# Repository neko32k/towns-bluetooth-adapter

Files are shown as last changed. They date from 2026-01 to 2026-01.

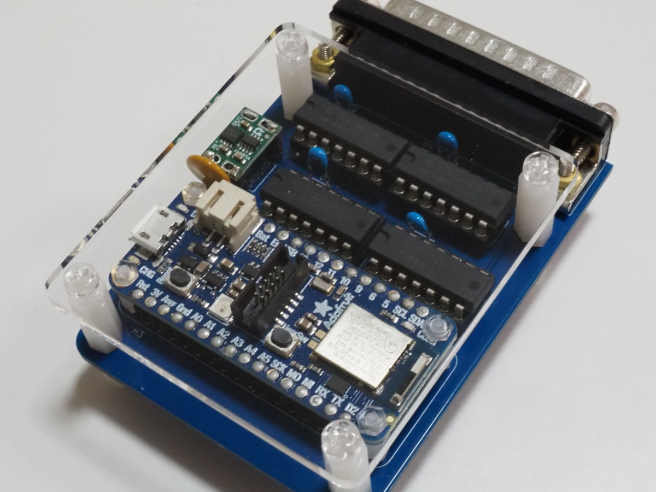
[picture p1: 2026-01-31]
assets/towns-bluetooth-adapter.jpg

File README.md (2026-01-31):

# FM TOWNS Bluetooth Adapter (towns-bluetooth-adapter)

This repository contains firmware, circuit diagrams, and documentation for a Bluetooth input adapter for FM TOWNS, using Adafruit Feather nRF52840. The goal is to enable modern Bluetooth keyboards, mice, and controllers to behave as HID devices for FM TOWNS systems.

このリポジトリは、Adafruit Feather nRF52840 を使用して FM TOWNS に Bluetooth 入力を追加するためのファームウェア、回路図、手順書をまとめたものです。Bluetooth キーボード／マウス／コントローラを FM TOWNS 側で HID として使えるようにすることを目標とします。

Disclaimer / 免責事項
- This project is an independent hobby project and is NOT affiliated with or endorsed by the FM TOWNS trademark owner or any commercial entity.
- 本プロジェクトは個人の趣味プロジェクトです。FM TOWNS の商標所有者や企業とは関係ありません。回路や接続による機器の故障や損害について作者は責任を負いません。実施は自己責任でお願いします。

Repository contents / 目次
- /arduino — Arduino スケッチ
- /kicad — KiCad プロジェクト（回路図・PCB）  
- /assets — 写真・動画・GIF  
- LICENSE — ライセンス（MIT）  

Requirements / 前提
- Adafruit Feather nRF52840 Express (or compatible)  
- FM TOWNS with accessible 5V power pin  
- Bluetooth input devices for testing

Companion blog / ブログ
- Project blog and notes: https://www.nk3-dev.net/  

Dependencies / 依存関係
This repository vendors `CircularQueue` (renamed to `CircularQueue.h`) from Francis‑Magallanes/CircularQueue.  
License: MIT — included in `licenses/CircularQueue_LICENSE.txt`.

本プロジェクトは `CircularQueue`（`CircularQueue.h` として同梱）を使用しています。上流は MIT ライセンスです（`licenses/CircularQueue_LICENSE.txt` を参照）。  
Included vendored file path: `arduino/bt_device/CircularQueue.h`

Affiliate disclosure / アフィリエイト表記
- Some links in this repository or the companion blog may be affiliate links (Amazon.co.jp Associate). 
- 本リポジトリおよび関連ブログには Amazon.co.jp 等のアフィリエイトリンクが含まれる場合があります。

License / ライセンス
This project is licensed under the MIT License — see the LICENSE file for details.  
本プロジェクトは MIT ライセンスで配布します。詳細は LICENSE を参照してください。

Author / 作者
- GitHub: neko32k  
- Year / 年: 2026

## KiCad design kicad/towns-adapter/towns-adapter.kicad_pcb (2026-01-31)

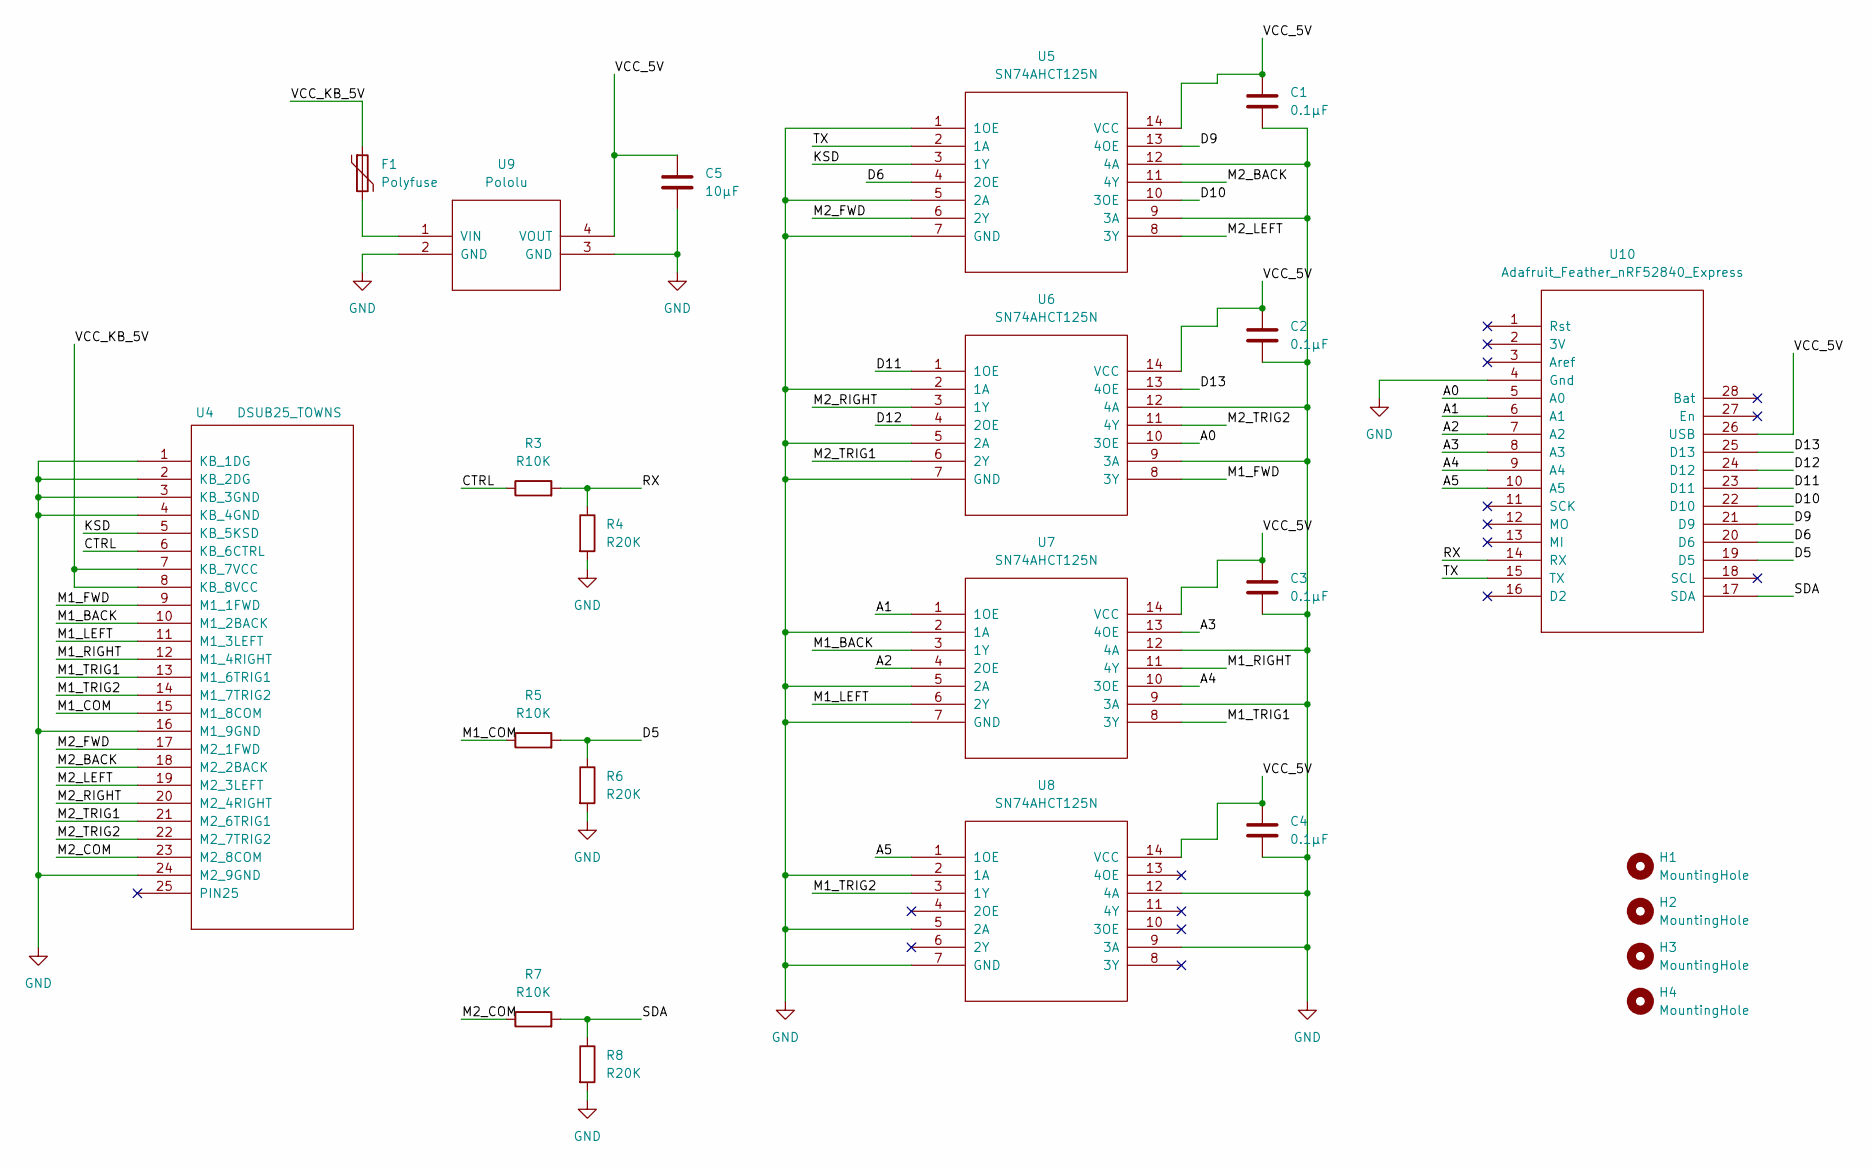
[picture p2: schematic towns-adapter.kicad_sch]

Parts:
C1, C2, C3, C4: 0.1μF; R_Axial_DIN0204_L3.6mm_D1.6mm_P5.08mm_Horizontal
C5: 10µF; CIP_CAPACITOR_C_1206_3216Metric_Pad1.33x1.80mm_HandSolder
F1: Polyfuse; R_Axial_DIN0204_L3.6mm_D1.6mm_P5.08mm_Horizontal
H1, H2, H3, H4: MountingHole; MountingHole_3.2mm_M3
R3, R5, R7: R10K; R_Axial_DIN0204_L3.6mm_D1.6mm_P7.62mm_Horizontal
R4, R6, R8: R20K; R_Axial_DIN0204_L3.6mm_D1.6mm_P7.62mm_Horizontal
U4: DSUB25_TOWNS; MODULE
U5, U6, U7, U8: SN74AHCT125N; MODULE
U9: Pololu; MODULE
U10: Adafruit_Feather_nRF52840_Express; MODULE

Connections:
/A0: U6.10 (3OE), U10.5 (A0)
/A1: U7.1 (1OE), U10.6 (A1)
/A2: U7.4 (2OE), U10.7 (A2)
/A3: U7.13 (4OE), U10.8 (A3)
/A4: U7.10 (3OE), U10.9 (A4)
/A5: U8.1 (1OE), U10.10 (A5)
/CTRL: R3.1, U4.6 (KB_6CTRL)
/D5: R5.2, R6.1, U10.19 (D5)
/D6: U5.4 (2OE), U10.20 (D6)
/D9: U5.13 (4OE), U10.21 (D9)
/D10: U5.10 (3OE), U10.22 (D10)
/D11: U6.1 (1OE), U10.23 (D11)
/D12: U6.4 (2OE), U10.24 (D12)
/D13: U6.13 (4OE), U10.25 (D13)
/KSD: U4.5 (KB_5KSD), U5.3 (1Y)
/M1_BACK: U4.10 (M1_2BACK), U7.3 (1Y)
/M1_COM: R5.1, U4.15 (M1_8COM)
/M1_FWD: U4.9 (M1_1FWD), U6.8 (3Y)
/M1_LEFT: U4.11 (M1_3LEFT), U7.6 (2Y)
/M1_RIGHT: U4.12 (M1_4RIGHT), U7.11 (4Y)
/M1_TRIG1: U4.13 (M1_6TRIG1), U7.8 (3Y)
/M1_TRIG2: U4.14 (M1_7TRIG2), U8.3 (1Y)
/M2_BACK: U4.18 (M2_2BACK), U5.11 (4Y)
/M2_COM: R7.1, U4.23 (M2_8COM)
/M2_FWD: U4.17 (M2_1FWD), U5.6 (2Y)
/M2_LEFT: U4.19 (M2_3LEFT), U5.8 (3Y)
/M2_RIGHT: U4.20 (M2_4RIGHT), U6.3 (1Y)
/M2_TRIG1: U4.21 (M2_6TRIG1), U6.6 (2Y)
/M2_TRIG2: U4.22 (M2_7TRIG2), U6.11 (4Y)
/RX: R3.2, R4.1, U10.14 (RX)
/SDA: R7.2, R8.1, U10.17 (SDA)
/TX: U5.2 (1A), U10.15 (TX)
/VCC_5V: C1.1, C2.1, C3.1, C4.1, C5.1, U5.14 (VCC), U6.14 (VCC), U7.14 (VCC), U8.14 (VCC), U9.4 (VOUT), U10.26 (USB)
/VCC_KB_5V: F1.1, U4.7 (KB_7VCC), U4.8 (KB_8VCC)
GND: C1.2, C2.2, C3.2, C4.2, C5.2, R4.2, R6.2, R8.2, U4.1 (KB_1DG), U4.2 (KB_2DG), U4.3 (KB_3GND), U4.4 (KB_4GND), U4.16 (M1_9GND), U4.24 (M2_9GND), U5.1 (1OE), U5.5 (2A), U5.7 (GND), U5.9 (3A), U5.12 (4A), U6.2 (1A), U6.5 (2A), U6.7 (GND), U6.9 (3A), U6.12 (4A), U7.2 (1A), U7.5 (2A), U7.7 (GND), U7.9 (3A), U7.12 (4A), U8.2 (1A), U8.5 (2A), U8.7 (GND), U8.9 (3A), U8.12 (4A), U9.2 (GND), U9.3 (GND), U10.4 (Gnd)
unnamed: F1.2, U9.1 (VIN)

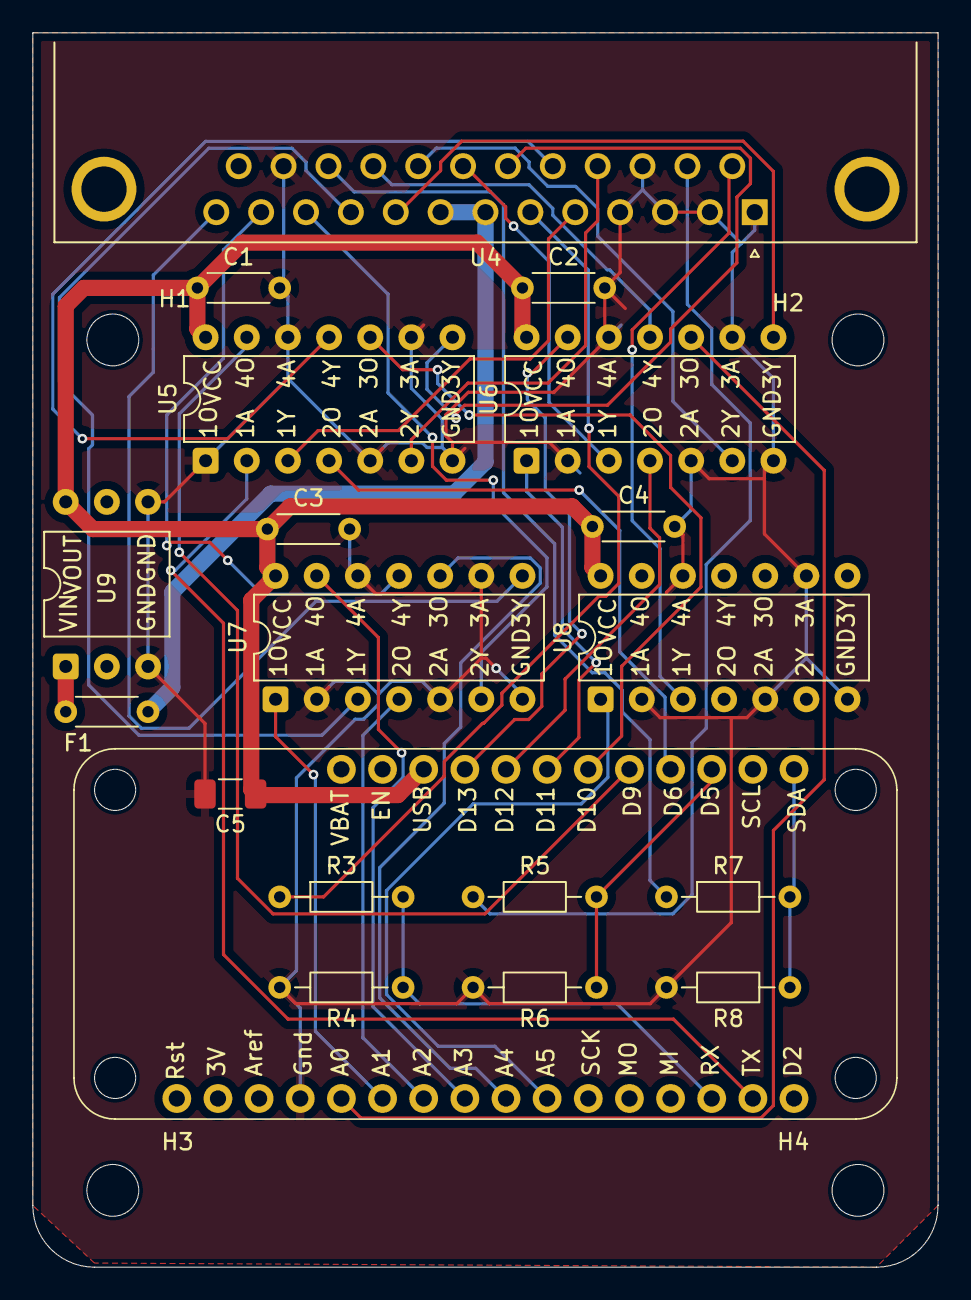
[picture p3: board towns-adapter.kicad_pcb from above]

Board: 2 copper layers, 55.9 x 76.2 mm, 23 parts (0 on the bottom side), 36 nets.

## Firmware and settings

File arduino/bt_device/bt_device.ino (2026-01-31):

#include <bluefruit.h>
#include <Wire.h>
#include "BLEClientHidAdafruitEx.h"
#include "CircularQueue.h"

// --- 設定 ---
#define MAX_CONNECTION    4
#define ENABLE_DEBUG_LOG  0
#define MOUSE_SCALE_NUM   2
#define MOUSE_SCALE_DENOM 3
#define ANALOG_THRESHOLD  10000
#define TURBO_INTERVAL_MS 31      // 連射間隔(ms). 31ms*2=62ms周期 -> 約16連射/秒

// キーボード送信設定
#define ENABLE_BATCH_KEY_PROCESS  // 定義するとキューを一括処理、未定義なら1ループ1キー
#define TOWNS_KEY_DELAY_MS 2      // プレフィックスとコードの間の遅延(ms)

// アクティブポート検出
volatile unsigned long last_strobe_detect_ms[2] = {0, 0};
volatile int active_mouse_port = -1; // -1:なし, 0:ポート0, 1:ポート1

#if ENABLE_DEBUG_LOG
  #define DBG_Printf(...)    Serial.printf(__VA_ARGS__)
  #define DBG_Print(...)     Serial.print(__VA_ARGS__)
  #define DBG_Println(...)   Serial.println(__VA_ARGS__)
#else
  #define DBG_Printf(...)
  #define DBG_Print(...)
  #define DBG_Println(...)
#endif

// --- ピン定義 (マウス / ジョイパッド) ---
// ポート0 ストロボ: SDA (22番ピン)
// ポート1 ストロボ: D5  (5番ピン)
const int PIN_STROBE_P0 = 22;
const int PIN_STROBE_P1 = 5;

// 出力ピン (0-5: ポート0, 6-11: ポート1)
// マッピング: 0=上/D0, 1=下/D1, 2=左/D2, 3=右/D3, 4=Trig1/A, 5=Trig2/B
// 物理ピン:
// P0: 6, 9, 10, 11, 12, 13
// P1: A0, A1, A2, A3, A4, A5
const uint8_t OUT_PINS[] = {
  6,  9, 10, 11, 12, 13,  // ポート 0
  A0, A1, A2, A3, A4, A5  // ポート 1
};

// --- マウスの状態 ---
volatile int16_t mouse_accum_x[2] = {0, 0}; 
volatile int16_t mouse_accum_y[2] = {0, 0};
volatile int16_t latch_x[2] = {0, 0};
volatile int16_t latch_y[2] = {0, 0};
volatile uint8_t mouse_btns[2] = {0, 0};
volatile uint8_t strobe_seq[2] = {0, 0};
volatile unsigned long last_strobe_us[2] = {0, 0};
unsigned long last_strobe_ms_check[2] = {0, 0};
bool has_mouse[2] = {false, false};

// --- キーボードの状態 ---
const uint8_t FMR_PREFIX_MAKE  = 0xA0; // 0x80 | 0x20(JIS)
const uint8_t FMR_PREFIX_BREAK = 0xB0; // 0x90 | 0x20(JIS)
#define FMR_KEY_TABLE_SIZE       256
const unsigned long SERIAL_BAUD = 9600;

struct KeyEvent {
  uint8_t code;
  bool isPress;
};
Queue<KeyEvent, 64> key_queue;

// --- Xboxコントローラー用レポート構造体 ---
typedef struct __attribute__((packed)) {
  int16_t x; int16_t y; int16_t z; int16_t rz;
  uint16_t brake; uint16_t gas;
  uint8_t hat; uint8_t btn1; uint8_t btn2; uint8_t padding;
} xbox_report_t;

typedef struct {
  uint16_t conn_handle;
  BLEClientHidAdafruitEx hid;
  hid_keyboard_report_t last_kbd_report;
  hid_mouse_report_t    last_mse_report;
  xbox_report_t         last_xbox_report;
} prph_info_t;

prph_info_t prphs[MAX_CONNECTION];

// --- FMRキーコード変換テーブル ---
uint8_t usb2fmr[FMR_KEY_TABLE_SIZE]; 

// --- ログバッファ ---
#if ENABLE_DEBUG_LOG
#define LOG_BUF_SIZE 64
typedef struct {
  unsigned long time;
  uint8_t port;
  uint8_t seq;
  int16_t latch;
  uint8_t nibble;
  uint8_t raw_pins; // D0-D3の状態 (ビットマスク)
  uint8_t strobe_level; // ストロボピンの状態
} strobe_log_t;

volatile strobe_log_t strobe_logs[LOG_BUF_SIZE];
volatile uint8_t log_head = 0;
volatile uint8_t log_tail = 0;

void push_strobe_log(uint8_t p, uint8_t s, int16_t l, uint8_t n, uint8_t pins, uint8_t st_lvl) {
  uint8_t next = (log_head + 1) % LOG_BUF_SIZE;
  if (next != log_tail) {
    strobe_logs[log_head].time = millis();
    strobe_logs[log_head].port = p;
    strobe_logs[log_head].seq = s;
    strobe_logs[log_head].latch = l;
    strobe_logs[log_head].nibble = n;
    strobe_logs[log_head].raw_pins = pins;
    strobe_logs[log_head].strobe_level = st_lvl;
    log_head = next;
  }
}
#endif

// --- 前方宣言 ---
void processKeyboardReport(hid_keyboard_report_t* report, hid_keyboard_report_t* last_report);
void processMouseReport(hid_mouse_report_t* report, hid_mouse_report_t* last_report, int port_idx);
void processXboxReport(xbox_report_t* report, xbox_report_t* last_report, int port_idx);
void sendTownsKey(uint8_t code, bool isPress);
void processKeyQueue();
void handleStrobe(int port_idx);
int findConnHandle(uint16_t conn_handle);
void initFMRTable();
void setOut(uint8_t pin_idx_local, bool bit_val, int port_base);

// --- コールバック ---
void kbd_callback_0(hid_keyboard_report_t* report) { processKeyboardReport(report, &prphs[0].last_kbd_report); }
void kbd_callback_1(hid_keyboard_report_t* report) { processKeyboardReport(report, &prphs[1].last_kbd_report); }
void kbd_callback_2(hid_keyboard_report_t* report) { processKeyboardReport(report, &prphs[2].last_kbd_report); }
void kbd_callback_3(hid_keyboard_report_t* report) { processKeyboardReport(report, &prphs[3].last_kbd_report); }

void mse_callback_0(hid_mouse_report_t* report) { processMouseReport(report, &prphs[0].last_mse_report, 0); }
void mse_callback_1(hid_mouse_report_t* report) { processMouseReport(report, &prphs[1].last_mse_report, 1); }
void mse_callback_2(hid_mouse_report_t* report) { processMouseReport(report, &prphs[2].last_mse_report, 0); }
void mse_callback_3(hid_mouse_report_t* report) { processMouseReport(report, &prphs[3].last_mse_report, 1); }

void (*kbd_callbacks[MAX_CONNECTION])(hid_keyboard_report_t*) = { kbd_callback_0, kbd_callback_1, kbd_callback_2, kbd_callback_3 };
void (*mse_callbacks[MAX_CONNECTION])(hid_mouse_report_t*)    = { mse_callback_0, mse_callback_1, mse_callback_2, mse_callback_3 };

// Xbox コールバック
void xbox_input_callback_impl(uint16_t conn_handle, uint8_t* data, uint16_t len) {
  if (len == 16) {
    int id = findConnHandle(conn_handle);
    if (id >= 0) {
      // ゲームパッド 1->ポート0, ゲームパッド 2->ポート1 にマッピング (ロジック: id % 2)
      processXboxReport((xbox_report_t*)data, &prphs[id].last_xbox_report, id % 2);
    }
  }
}
void xbox_callback_0(BLEClientCharacteristic* chr, uint8_t* data, uint16_t len) { xbox_input_callback_impl(prphs[0].conn_handle, data, len); }
void xbox_callback_1(BLEClientCharacteristic* chr, uint8_t* data, uint16_t len) { xbox_input_callback_impl(prphs[1].conn_handle, data, len); }
void xbox_callback_2(BLEClientCharacteristic* chr, uint8_t* data, uint16_t len) { xbox_input_callback_impl(prphs[2].conn_handle, data, len); }
void xbox_callback_3(BLEClientCharacteristic* chr, uint8_t* data, uint16_t len) { xbox_input_callback_impl(prphs[3].conn_handle, data, len); }
void (*xbox_callbacks[MAX_CONNECTION])(BLEClientCharacteristic*, uint8_t*, uint16_t) = { xbox_callback_0, xbox_callback_1, xbox_callback_2, xbox_callback_3 };

// --- ISRラッパー ---
void isr_strobe_p0() { handleStrobe(0); }
void isr_strobe_p1() { handleStrobe(1); }

void setup() {
#if ENABLE_DEBUG_LOG
  Serial.begin(115200);
#endif
  DBG_Println("Towns BT Adapter: Integrated Firmware");

  initFMRTable();

  // GPIO 設定
  for (int i=0; i<12; i++) {
    pinMode(OUT_PINS[i], OUTPUT);
    digitalWrite(OUT_PINS[i], HIGH);
  }
  pinMode(PIN_STROBE_P0, INPUT_PULLUP);
  pinMode(PIN_STROBE_P1, INPUT_PULLUP);
  attachInterrupt(digitalPinToInterrupt(PIN_STROBE_P0), isr_strobe_p0, CHANGE);
  attachInterrupt(digitalPinToInterrupt(PIN_STROBE_P1), isr_strobe_p1, CHANGE);

  // キーボード用UART (nRF52 featherではSerial1が標準)
  Serial1.begin(SERIAL_BAUD, SERIAL_8E1);

  // BLE設定
  Bluefruit.begin(0, MAX_CONNECTION);
  Bluefruit.setName("Towns BT Adapter");
  Bluefruit.setConnLedInterval(250);
  
  for (uint8_t i=0; i<MAX_CONNECTION; i++) {
    prphs[i].conn_handle = BLE_CONN_HANDLE_INVALID;
    prphs[i].hid.begin();
    memset(&prphs[i].last_kbd_report, 0, sizeof(hid_keyboard_report_t));
    memset(&prphs[i].last_mse_report, 0, sizeof(hid_mouse_report_t));
    memset(&prphs[i].last_xbox_report, 0, sizeof(xbox_report_t));
    prphs[i].last_xbox_report.hat = 8; // Hat center (released) initialization
    
    prphs[i].hid.setKeyboardReportCallback(kbd_callbacks[i]);
    prphs[i].hid.setMouseReportCallback(mse_callbacks[i]);
  }

  Bluefruit.Central.setConnectCallback(connect_callback);
  Bluefruit.Central.setDisconnectCallback(disconnect_callback);
  Bluefruit.Security.setSecuredCallback(connection_secured_callback);
  
  Bluefruit.Scanner.setRxCallback(scan_callback);
  Bluefruit.Scanner.restartOnDisconnect(true);
  Bluefruit.Scanner.setInterval(160, 80); 
  Bluefruit.Scanner.filterUuid(BLEUuid(0x1812)); 
  Bluefruit.Scanner.useActiveScan(true);
  Bluefruit.Scanner.start(0); 
}

void loop() {
  unsigned long now = millis();
  
  // キーキューの処理
  processKeyQueue();

  // --- ログ出力 ---
#if ENABLE_DEBUG_LOG
  while (log_head != log_tail) {
      strobe_log_t l;
      l.time     = strobe_logs[log_tail].time;
      l.port     = strobe_logs[log_tail].port;
      l.seq      = strobe_logs[log_tail].seq;
      l.latch    = strobe_logs[log_tail].latch;
      l.nibble   = strobe_logs[log_tail].nibble;
      l.raw_pins = strobe_logs[log_tail].raw_pins;
      l.strobe_level = strobe_logs[log_tail].strobe_level;
      
      log_tail = (log_tail + 1) % LOG_BUF_SIZE;
      
      DBG_Printf("[Port%d P:%d] Strobe:%d Latch:%d Nib:%X PinOut:%02X\n", 
                 l.port, l.seq, l.strobe_level, l.latch, l.nibble, l.raw_pins);
  }
#if ENABLE_DEBUG_LOG
  static unsigned long last_alive = 0;
  if (now - last_alive > 5000) {
     DBG_Println("[Sys] Status Report:");
     for(int p=0; p<2; p++) {
        unsigned long idle = now - last_strobe_ms_check[p];
        DBG_Printf("  Port%d: MouseMode=%d, StrobeIdle=%lums, GpdActive=%d\n", 
                   p, has_mouse[p], idle, (idle >= 200 && !has_mouse[p]));
     }
     last_alive = now;
  }
#endif
#endif

  // ゲームパッド出力の更新 (マウスモードでない場合)
  for(int p=0; p<2; p++) {
    // マウスモードが有効な場合でも、このポートが「アクティブなマウスポート」として確定していない場合は
    // ゲームパッドとして振る舞うことを許可する（これが「そうで無い方はゲームパッドにする」の実装）。
    // active_mouse_port は handleStrobe() で TOWNSからのストロボ信号を受けたときに更新される。
    if (has_mouse[p] && active_mouse_port == p) {
       continue;
    }

    // 最近ストロボがあった場合（レガシーチェック）、スキップ
    // FM-TOWNS本体が常にストロボ信号(ポート7)をポーリングしている可能性がある。
    // その場合、ここでブロックするとゲームパッド信号が出力されないため、コメントアウトする。
    // (マウスモードの排他制御は has_mouse[p] で十分に行われている)
    // if (now - last_strobe_ms_check[p] < 200) {
    //    continue; 
    // }
    
    // このポートのアクティブなゲームパッドを探す
    xbox_report_t* xb = NULL;
    
    // 【修正】1台のコントローラー(ID=0)だけでポート0/1の両方を操作可能にする(接続ミスやポート入替対策)
    // ID=0がつながっていて、このポートに対応する専用ID(p, p+2...)がつながっていない場合、ID=0を使う。
    bool specific_device_found = false;
    for(int id=p; id<MAX_CONNECTION; id+=2) { 
       if (prphs[id].conn_handle != BLE_CONN_HANDLE_INVALID && prphs[id].hid.gamepadPresent()) {
          xb = &prphs[id].last_xbox_report;
          specific_device_found = true;
          break; 
       }
    }
    // 専用デバイスが見つからず、かつID=0(Player1)が存在すれば、それをミラーリングで使用する
    if (!specific_device_found && prphs[0].conn_handle != BLE_CONN_HANDLE_INVALID && prphs[0].hid.gamepadPresent()) {
       xb = &prphs[0].last_xbox_report;
    }

    // --- 出力値の計算とログ ---
    bool out_vals[6]; // 0:U, 1:D, 2:L, 3:R, 4:A, 5:B (物理出力値)
    
    if (xb) {
       // ロジックマッピング : ハット または アナログ
       bool u = false, d = false, l = false, r = false;
       
       // ハットスイッチ (1-based mapping: 0=Center, 1=Up, 2=UR, ..., 8=UL)
       // ログ解析により、このコントローラーは「放すと0」を出力し、
       // 「下を押すと5」を出力することが判明したため、1-based (0=Center) として扱う。
       if (xb->hat > 0 && xb->hat <= 8) {
          // ビットマスク: 上=1, 下=2, 左=4, 右=8
          // Index: 0=Up, 1=UR, 2=R, 3=DR, 4=D, 5=DL, 6=L, 7=UL
          static const uint8_t HAT_BITS[] = { 1, 9, 8, 10, 2, 6, 4, 5 };
          uint8_t bits = HAT_BITS[xb->hat - 1]; // 1-basedなのを0-basedに補正
          if (bits & 1) u = true;
          if (bits & 2) d = true;
          if (bits & 4) l = true;
          if (bits & 8) r = true;
       }
       
       // アナログスティック (Unsigned 16bit 0-65535, Center 32768 と仮定して補正)
       // int16_tとして読み込まれているため、0x8000(-32768)付近がセンターとなる
       // キャストしてオフセットを引くことで 0中心の ±32767 に変換
       int32_t val_x = (uint16_t)xb->x - 32768;
       int32_t val_y = (uint16_t)xb->y - 32768;

       // y軸反転: 通常GamePadは上が0(Min) 下が65535(Max) -> 補正後 上が-32768, 下が+32767
       // Towns仕様や好みによるが、ここでは標準的な "上がマイナス" を前提にロジックを組む
       
       if (val_y >  ANALOG_THRESHOLD) d = true; else if (val_y < -ANALOG_THRESHOLD) u = true;
       if (val_x >  ANALOG_THRESHOLD) r = true; else if (val_x < -ANALOG_THRESHOLD) l = true;

       // ボタン (Xbox A=Btn1(0x01), B=Btn1(0x02), X=0x04, Y=0x08)
       // Towns: Trig1(A), Trig2(B)
       // ユーザー要望: X->連射A, Y->連射B
       // 連射サイクル: TURBO_INTERVAL_MS * 2
       bool turbo = (millis() / TURBO_INTERVAL_MS) % 2;
       
       bool rawA = (xb->btn1 & 0x01); // A
       bool rawB = (xb->btn1 & 0x02); // B
       // ログ解析による確定ビットマスク
       // X: Btn:0008 -> 0x08
       // Y: Btn:0010 -> 0x10
       bool rawX = (xb->btn1 & 0x08); 
       bool rawY = (xb->btn1 & 0x10); 

       // マッピング (btnA=実機A, btnB=実機B と確定)
       // X(0x08) -> 連射A
       // Y(0x10) -> 連射B
       bool btnA = rawA || (rawX && turbo);
       bool btnB = rawB || (rawY && turbo);

       // SELECT / RUN 対応 (FM-TOWNS仕様)
       // ユーザー指定:
       //   Btn:0400 (Select/Back) -> SELECT -> 上下同時 (u + d)
       //   Btn:0800 (Start/Menu)  -> RUN    -> 左右同時 (l + r)
       uint16_t raw_btns = xb->btn1 | (xb->btn2 << 8);
       
       if (raw_btns & 0x0400) { // Select/Back -> SELECT (上下)
           u = true; d = true; 
       }
       if (raw_btns & 0x0800) { // Start/Menu -> RUN (左右)
           l = true; r = true;
       }
       
       // 出力を決定 (Active Low: 押下=false(0), 解放=true(1))
       // 以前 "Val:00" (All Low) で「接続時に何か押された」＝LOWが押下判定であることを確認。
       // したがって、押下(true)の場合はfalse(LOW)を出力する。
       out_vals[0] = !u;
       out_vals[1] = !d;
       out_vals[2] = !l;
       out_vals[3] = !r;
       out_vals[4] = !btnA;
       out_vals[5] = !btnB;

    } else {
       // 全てリリース (Active Lowなので HIGH=true を出力)
       for(int i=0; i<6; i++) out_vals[i] = true;
    }

#if ENABLE_DEBUG_LOG
    static uint8_t last_out_bits[2] = {0xFF, 0xFF};
    uint8_t current_bits = 0;
    for(int i=0; i<6; i++) {
      if (out_vals[i]) current_bits |= (1 << i);
    }
    
    if (current_bits != last_out_bits[p]) {
      // 変化があった場合ログ出力
      // ビット順: 0(Up), 1(Dn), 2(Lf), 3(Rt), 4(A), 5(B) ※physical value
      DBG_Printf("[GPD Out Port%d] Val:%02X (U:%d D:%d L:%d R:%d A:%d B:%d)\n", 
                 p, current_bits, 
                 out_vals[0], out_vals[1], out_vals[2], out_vals[3], out_vals[4], out_vals[5]);
      last_out_bits[p] = current_bits;
    }
#endif

    // 実際の出力
    for(int i=0; i<6; i++) {
       setOut(i, out_vals[i], p);
    }
  }
}

// --- ロジック ---
void setOut(uint8_t pin_idx_local, bool bit_val, int port_base) {
  // pin_idx_local: 0-5
  // OUTPUT: LOW=Active(押下) ジョイパッド用, またはマウス用のビット値
  // バッファ(SN74AHCT125N)を使用しているため、Featherからは常にCMOSレベル(High/Low)を出力する。
  // 3.3V High -> Buffer -> 5V High
  // 0V Low    -> Buffer -> 0V Low
  int pin = OUT_PINS[port_base * 6 + pin_idx_local];
  digitalWrite(pin, bit_val ? HIGH : LOW);
}

void handleStrobe(int p) {
  unsigned long now = micros();
  int strobe_pin = (p == 0) ? PIN_STROBE_P0 : PIN_STROBE_P1;
  uint8_t st_lvl = digitalRead(strobe_pin);

  // マウス接続がない場合、ストロボ信号は無視する (ゲームパッド等への干渉を防ぐ)
  // 特に、タイムアウト処理でピンをHIGH(Release)に戻す処理が走ると、
  // ゲームパッドのボタン押しっぱなし(LOW)状態が解除されてしまうため。
  if (!has_mouse[p]) {
     return;
  }

  // アクティブなマウスポート検出を更新
  last_strobe_detect_ms[p] = millis();
  active_mouse_port = p;

  // タイムアウトリセット (時間 > 3ms)
  if ((now - last_strobe_us[p]) > 3000) {
      strobe_seq[p] = 0;
      // アイドル時はピンを解放(HIGH)して、スタックビットによるドリフトを防ぐ
      for(int i=0; i<6; i++) setOut(i, true, p); 
  }
  
  last_strobe_ms_check[p] = millis();

  // マウスが接続されていない場合は、ログ出力のみで戻る（ピンを駆動しない）
  // if (!has_mouse[p]) {
  //    return;
  // }

  int16_t val16 = 0;

  // シーケンス0でXをラッチ
  if (strobe_seq[p] == 0) {
      // 剰余を保持したスケーリングロジック
      int16_t move = (mouse_accum_x[p] * MOUSE_SCALE_NUM) / MOUSE_SCALE_DENOM;
      if (move != 0) {
          int16_t consumed = (move * MOUSE_SCALE_DENOM) / MOUSE_SCALE_NUM;
          mouse_accum_x[p] -= consumed;
          latch_x[p] = move;
      } else {
          latch_x[p] = 0;
      }
      
      // 8ビット範囲にクランプ
      if (latch_x[p] > 127) latch_x[p] = 127;
      if (latch_x[p] < -127) latch_x[p] = -127;
      
      val16 = latch_x[p];
  } 
  else if (strobe_seq[p] == 1) {
      val16 = latch_x[p];
  }
  // シーケンス2でYをラッチ
  else if (strobe_seq[p] == 2) {
      // 剰余を保持したスケーリングロジック
      int16_t move = (mouse_accum_y[p] * MOUSE_SCALE_NUM) / MOUSE_SCALE_DENOM;
      if (move != 0) {
          int16_t consumed = (move * MOUSE_SCALE_DENOM) / MOUSE_SCALE_NUM;
          mouse_accum_y[p] -= consumed;
          latch_y[p] = move;
      } else {
          latch_y[p] = 0;
      }

      // クランプ
      if (latch_y[p] > 127) latch_y[p] = 127;
      if (latch_y[p] < -127) latch_y[p] = -127;

      val16 = latch_y[p];
  } 
  else {
      val16 = latch_y[p];
  }

  int8_t val8 = (int8_t)val16;
  bool first = (strobe_seq[p] % 2 == 0);
  
  // ニブル出力 (上位 -> 下位)
  uint8_t nib = first ? ((val8 >> 4) & 0x0F) : (val8 & 0x0F);
  
  // D0-D3への出力 (標準ロジック)
  // Townsはこれらのピンでマウスデータを期待する
#if ENABLE_DEBUG_LOG
  uint8_t pins_val = 0;
#endif
  for (int i=0; i<4; i++) {
      bool bit = (nib >> i) & 1;
      // ロジック反転要求 (ユーザー戦略)
      // "反転ロジックでドリフトは止まった"。
      // 現在: !bit (Active Low)。
      // 以前ドリフトに効いたのは: bit (Active High)。
      // そのためここでは bit (Active High) を使用し、accum を -= で補正する。
      setOut(i, bit, p);
#if ENABLE_DEBUG_LOG
      // 物理レベルのログ記録
      if (bit) pins_val |= (1 << i); 
#endif
  }

  // リングバッファへのログ記録
#if ENABLE_DEBUG_LOG
  push_strobe_log(p, strobe_seq[p], val16, nib, pins_val, st_lvl);
#endif
  
  // ボタン出力 (Active Low)
  bool left = (mouse_btns[p] & 1);
  bool right = (mouse_btns[p] & 2);
  setOut(4, !left, p); 
  setOut(5, !right, p);
  
  strobe_seq[p] = (strobe_seq[p] + 1) & 0x03;
  last_strobe_us[p] = now;
}

// BLE 標準コールバック
void scan_callback(ble_gap_evt_adv_report_t* report) { Bluefruit.Central.connect(report); }

void connect_callback(uint16_t conn_handle) {
  int id = findConnHandle(BLE_CONN_HANDLE_INVALID);
  if (id < 0) { Bluefruit.disconnect(conn_handle); return; }
  
  prphs[id].conn_handle = conn_handle;
  // 新規接続時にレポート構造体をクリア（特にHatをニュートラルに）
  memset(&prphs[id].last_kbd_report, 0, sizeof(hid_keyboard_report_t));
  memset(&prphs[id].last_mse_report, 0, sizeof(hid_mouse_report_t));
  memset(&prphs[id].last_xbox_report, 0, sizeof(xbox_report_t));
  prphs[id].last_xbox_report.hat = 8;

  prphs[id].hid.discover(conn_handle);
  Bluefruit.Connection(conn_handle)->requestPairing();
  Bluefruit.Scanner.start(0);

  DBG_Printf("[Connect] ID: %d, Handle: %d\n", id, conn_handle);
}

void connection_secured_callback(uint16_t conn_handle) {
  int id = findConnHandle(conn_handle);
  if (id < 0) return;
  prph_info_t* peer = &prphs[id];

  DBG_Printf("[Secured] ID: %d\n", id);

#if ENABLE_DEBUG_LOG
  BLEConnection* conn = Bluefruit.Connection(conn_handle);
  char devName[32] = { 0 };
  if ( conn->getPeerName(devName, sizeof(devName)) ) {
    DBG_Printf(" - Name: %s\n", devName);
  }
  
  uint8_t hidInfo[4];
  if ( peer->hid.getHidInfo(hidInfo) ) {
    DBG_Printf(" - HID Ver: %d.%d, Country: %d, Flags: 0x%02X\n", hidInfo[0], hidInfo[1], hidInfo[2], hidInfo[3]);
  }

  DBG_Print(" - Protocol: ");
  if (peer->hid.gamepadPresent()) DBG_Print("Gamepad ");
  if (peer->hid.keyboardPresent()) DBG_Print("Keyboard ");
  if (peer->hid.mousePresent()) DBG_Print("Mouse ");
  DBG_Println();
#endif
  
  if (peer->hid.gamepadPresent() && !peer->hid.keyboardPresent()) {
     peer->hid.setBootMode(false);
     if (peer->hid.enableGamepad()) {
       peer->hid.getGamepadReportCharacteristic().setNotifyCallback(xbox_callbacks[id]);
       DBG_Println(" - Xbox Raw Mode: Enabled");
     }
  } else {
     peer->hid.setBootMode(true);
     if (peer->hid.keyboardPresent()) peer->hid.enableKeyboard();
     if (peer->hid.mousePresent()) {
       peer->hid.enableMouse();
       int p = id % 2;
       // マウスは物理的にどのポートに挿されるか不明であり(ケーブル検知不可)、
       // TOWNSからのストロボ信号(ポーリング)に基づいて応答する必要があるため、
       // どちらのポートからのストロボも受け付けるように両方のフラグを立てておく。
       // 実際にどちらに応答するかは handleStrobe() 内の active_mouse_port で動的に決まる。
       has_mouse[0] = true; 
       has_mouse[1] = true;
       // 接続時のドリフトを防ぐためにアキュムレータをリセット
       mouse_accum_x[p] = 0;
       mouse_accum_y[p] = 0;
       latch_x[p] = 0;
       latch_y[p] = 0;
       strobe_seq[p] = 0;
       mouse_btns[p] = 0; 
     }
     DBG_Println(" - Boot Mode: Enabled (KBD/MSE)");
  }
}

void disconnect_callback(uint16_t conn_handle, uint8_t reason) {
  int id = findConnHandle(conn_handle);
  if (id >= 0) {
    if (prphs[id].hid.mousePresent()) has_mouse[id % 2] = false;
    prphs[id].conn_handle = BLE_CONN_HANDLE_INVALID;
  }
  DBG_Printf("[Disconnect] Handle: %d, Reason: 0x%02X\n", conn_handle, reason);
}

int findConnHandle(uint16_t conn_handle) {
  for(int id=0; id<MAX_CONNECTION; id++) if(conn_handle == prphs[id].conn_handle) return id;
  return -1;
}

void processMouseReport(hid_mouse_report_t* report, hid_mouse_report_t* last_report, int p) {
  // このポートがデータを受信すべきか判定。
  // 'p' が現在のアクティブなポートである場合、またはまだアクティブなポートがない場合にのみデータを送る。
  // コールバックは 'p' をハードコードしているが、
  // 代わりに、データを「アクティブなポート」にルーティングする。
  
  int target_port = active_mouse_port;
  if (target_port == -1) {
     // ストロボがまだ検出されていない場合はマッピングされたポートをデフォルトとする
     target_port = p % 2; 
  }

  // 強制反転ロジックテスト:
  // ユーザー報告 "ロジック反転でドリフトは止まったが動作が反転した"。
  // そのため、setOutでロジックを反転(Active High -> Active Low) し、かつ 移動アキュムレータも反転する。
  // これにより物理的には "反転ビット" を送るが、論理的には "反転値" となる。
  // ここでアキュムレータを反転(減算)してみる。
  
  mouse_accum_x[target_port] -= report->x; 
  mouse_accum_y[target_port] -= report->y;
  mouse_btns[target_port] = report->buttons; 
  
  if (report->x != 0 || report->y != 0 || report->buttons != last_report->buttons) {
     DBG_Printf("[MSE %d->%d] In(X:%d Y:%d) -> Accum(X:%d Y:%d)\n", p, target_port, report->x, report->y, mouse_accum_x[target_port], mouse_accum_y[target_port]);
  }

  memcpy(last_report, report, sizeof(hid_mouse_report_t));
}
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
